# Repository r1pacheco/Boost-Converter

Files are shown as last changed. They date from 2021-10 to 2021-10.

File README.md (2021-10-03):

# Boost-Converter

<h3>This board was designed specifically for the R3 rover and has major restraints that were followed: </h3>

* Maximum dimensions of 42mm x 48mm x 23mm to remain inside the restrictions of the PDB (Power Distribution Board)
* Header space is required so parts do not overlap or bump edges as it is a tight fit within the chasis and the Molex connectors 
* Needs to handle a minimum of 5 amps and increase voltage from 15 to 24 volts minimum (my actual design uses a 5KΩ potentiometer to vary the desired voltage at the output, to make it more flexible for future use if needed)

|Top Side|Bottom Side|
|---|---|
|boost-board-top|boost-board-bot|  

*Click the above photos for a larger view*

<h3>Details and considerations made to improve the boards design and functionality:</h3>

* Thick traces or polygons are used to handle large current as well as act as heat displacers 
* Room for large external heat sinks was needed to help cool down the MOSFET and large diode on the board since they handle the bulk of the current
* Vias were also used to help give direct air flow to the main IC and fuse holder 
* a physical cutout (notch) was placed in the PCB beside the horizontal fuse holder, making it easier to set/remove the fuses (they can be tight sometimes)
* Large polygons were used where the most current would travel to make sure traces did not burn up and can disipate as much heat as possible
* all large capacitors/inductors were kept to one side of the board so they would not interfere with external Molex connectors on the PDB board. This is needed since the right side of the board will be overlapping pre-existing components and we needed the compensated space
* LED indication tells the user if the board is being used and is working properly
* overall board size was given tolerances of 1mm x 1mm x 1mm so they did not interfere with other external boards. Chamfers were also added for the same reason

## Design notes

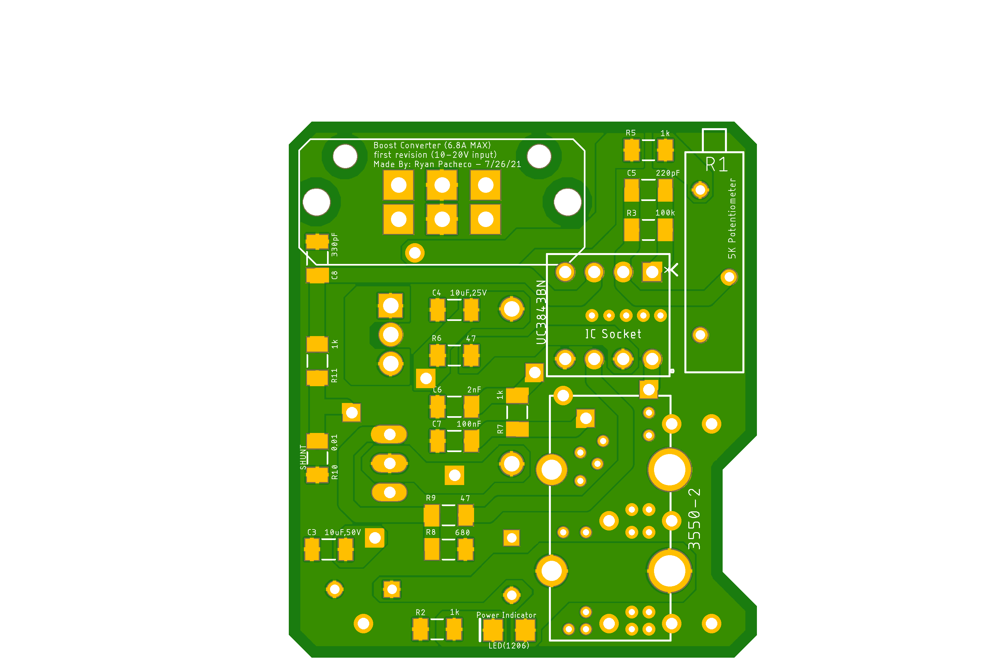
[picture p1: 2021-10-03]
photos/boost-board-top.png

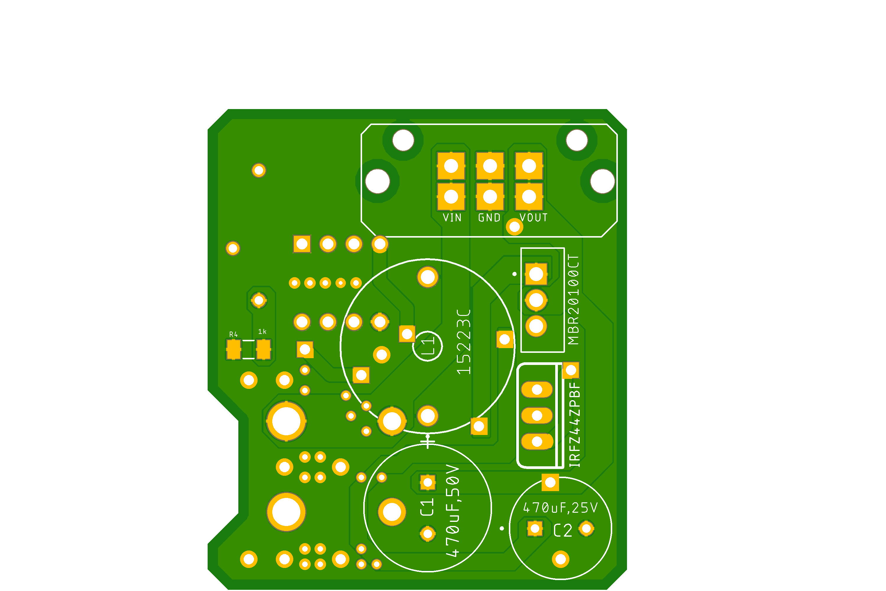
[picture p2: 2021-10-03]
photos/boost-board-bot.png

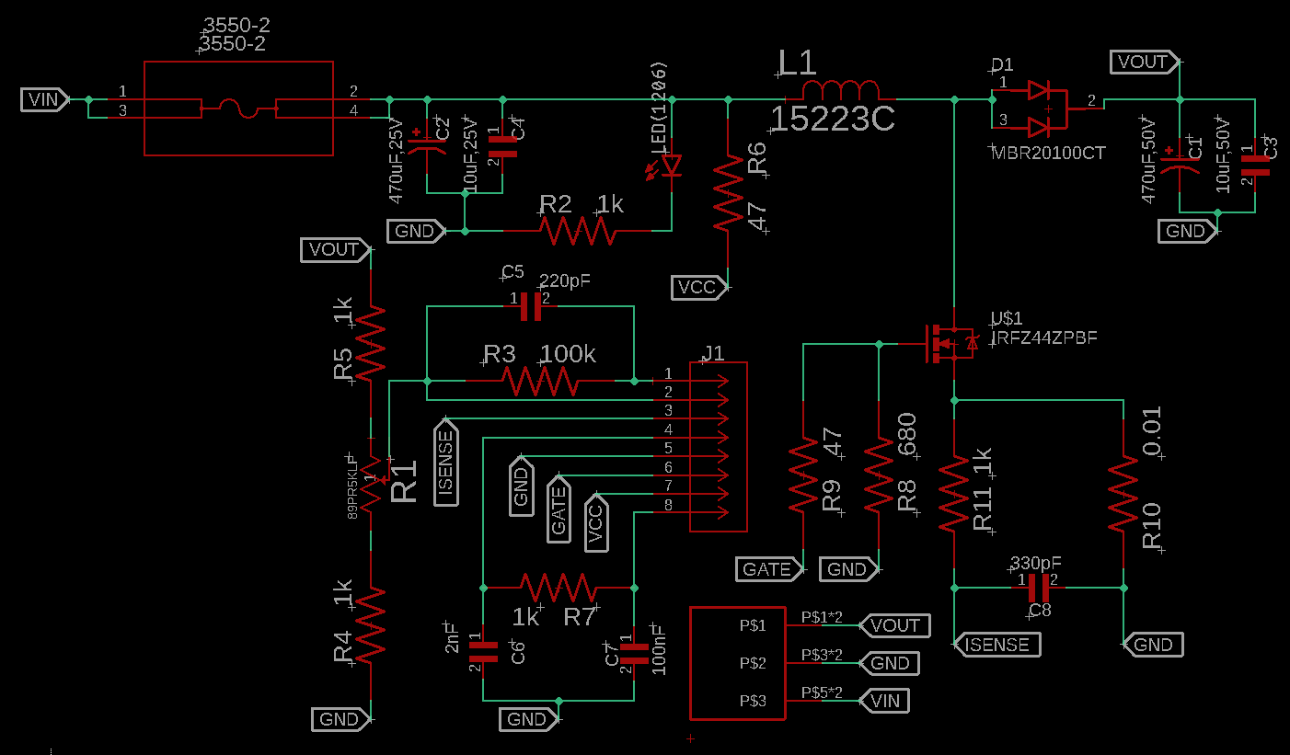
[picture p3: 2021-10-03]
photos/Boost_schm.png

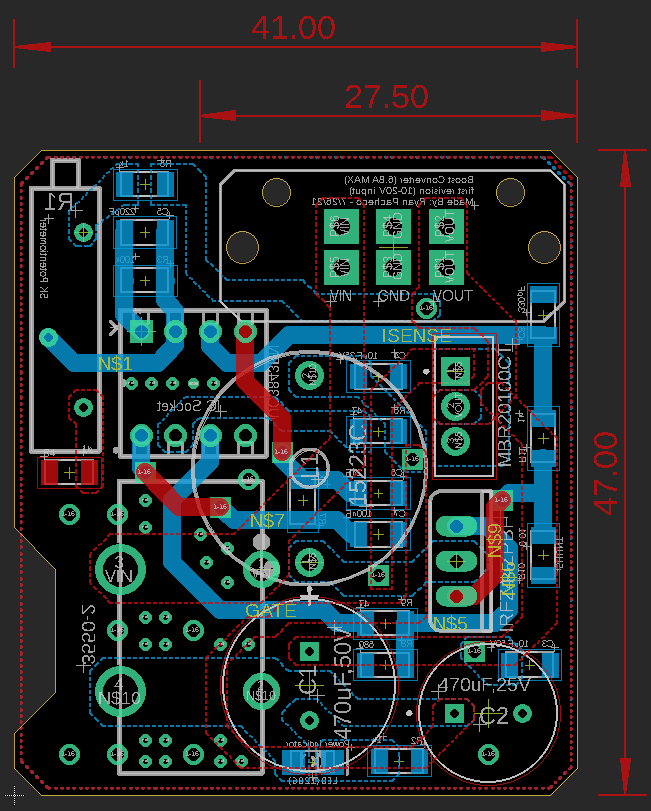
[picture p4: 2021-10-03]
photos/Boost_brd.png

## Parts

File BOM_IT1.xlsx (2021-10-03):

PARTS | SUPPLIER | PRICE | LINK
Fuse Holder | DigiKey | $1.83 | https://www.digikey.ca/en/products/detail/keystone-electronics/3550-2/2137310
Fuse | DigiKey | $0.39 | https://www.digikey.ca/en/products/detail/littelfuse-inc/029707-5WXNV/146586
IC Socket | DigiKey | $0.27 | https://www.digikey.ca/en/products/detail/amphenol-fci/DILB8P-223TLF/4292069?productid=4292069
Switcher/Regulator IC | DigiKey | $1.31 | https://www.digikey.ca/en/products/detail/stmicroelectronics/UC3843BN/1665279
Diode Rectifier (Schottky) | DigiKey | $1.99 | https://www.digikey.ca/en/products/detail/on-semiconductor/MBRF30L45CTG/1792235
N-CH Mosfet | DigiKey | $1.36 | https://www.digikey.ca/en/products/detail/infineon-technologies/IRFZ44ZPBF/811766
Inductor (22uH) | DigiKey | $2.48 | https://www.digikey.ca/en/products/detail/murata-power-solutions-inc/15223C/5798142
Input Cap (electrolytic, 470uF, 25V) | DigiKey | $0.81 | https://www.digikey.ca/en/products/detail/rubycon/25YXG470MEFCT810X16/9553868
Output Cap (electrolytic, 470uF, 50V) | DigiKey | $1.35 | https://www.digikey.ca/en/products/detail/rubycon/50YXG470MEFC12-5X20/3564033
Resistor Trimmer (5K) | DigiKey | $2.49 | https://www.digikey.ca/en/products/detail/tt-electronics-bi/89PR5KLF/2408743
Resistor Shunt (10mOhm) | DigiKey | $0.80 | https://www.digikey.ca/en/products/detail/riedon/CSR1206-0R01F1/2813292
Random Resistors (1206 size) | DigiKey
Random Capacitors (1206 size) | DigiKey
heat sink | DigiKey |  | https://www.digikey.ca/en/products/detail/cui-devices/HSE-B20350-NP/7319885
heat sink | DigiKey |  | https://www.digikey.ca/en/products/detail/assmann-wsw-components/V7236A1/3476149
TOTAL | - | $15.08 | (not including PCB price)

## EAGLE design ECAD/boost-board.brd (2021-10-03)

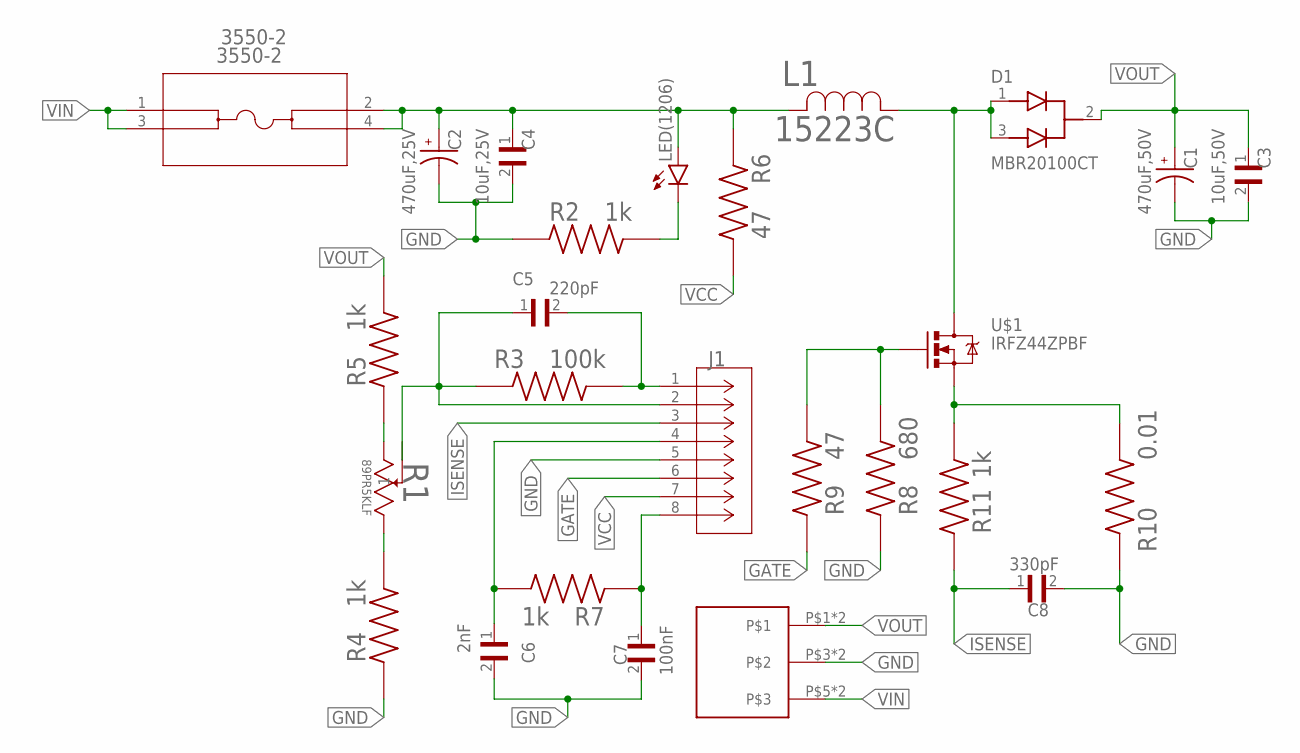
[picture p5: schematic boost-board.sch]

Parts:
3550-2: 3550-2; 3550-2_KEY
C1: 470uF,50V; CAPPRD500W60D1250H2200
C2: 470uF,25V; CAPPRD500W60D1000H1800
C3: 10uF,50V; CAPC3216X88N
C4: 10uF,25V; CAPC3216X88N
C5: 220pF; CAPC3216X88N
C6: 2nF; CAPC3216X88N
C7: 100nF; CAPC3216X88N
C8: 330pF; CAPC3216X88N
D1: MBR20100CT; TO254P1066X482X2286-3
J1: DILB8P-223TLF; CONN_DILB8P-223TLF_AMP
L1: 15223C; 15223C_MUR
LED(1206): LED-FKIT-1206; FKIT-LED-1206
R1: 89PR5KLF; RES3_89P_TTE
R2, R4, R5, R7, R11: 1k; RESC3216X70N
R3: 100k; RESC3216X70N
R6, R9: 47; RESC3216X70N
R8: 680; RESC3216X70N
R10: 0.01; RESC3216X70N
U$1: IRFZ44ZPBF; TO-220
U$2: FX30B-3S-3.81DSA; FX30B-4S-3.81DSA

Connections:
GATE: J1.6, R9.1
GND: C1.N, C2.N, C3.2, C4.2, C6.2, C7.2, C8.2, J1.5, R2.1, R4.1, R8.1, R10.1, U$2.P$3, U$2.P$4
ISENSE: C8.1, J1.3, R11.1
unnamed: C5.1, J1.2, R1.2, R3.1
unnamed: C5.2, J1.1, R3.2
unnamed: R1.1 (3), R4.2
unnamed: R1.3 (1), R5.1
unnamed: R8.2, R9.2, U$1.1 (G)
unnamed: D1.1 (ANODE1), D1.3 (ANODE2), L1.1, U$1.2 (D)
unnamed: C7.1, J1.8, R7.1
unnamed: LED(1206).C, R2.2
unnamed: R10.2, R11.2, U$1.3 (S)
unnamed: 3550-2.2, 3550-2.4, C2.P, C4.1, L1.2, LED(1206).A, R6.2
unnamed: C6.1, J1.4, R7.2
VCC: J1.7, R6.1
VIN: 3550-2.1, 3550-2.3, U$2.P$5, U$2.P$6
VOUT: C1.P, C3.1, D1.2 (COMMON_CATHODE), R5.2, U$2.P$1, U$2.P$2

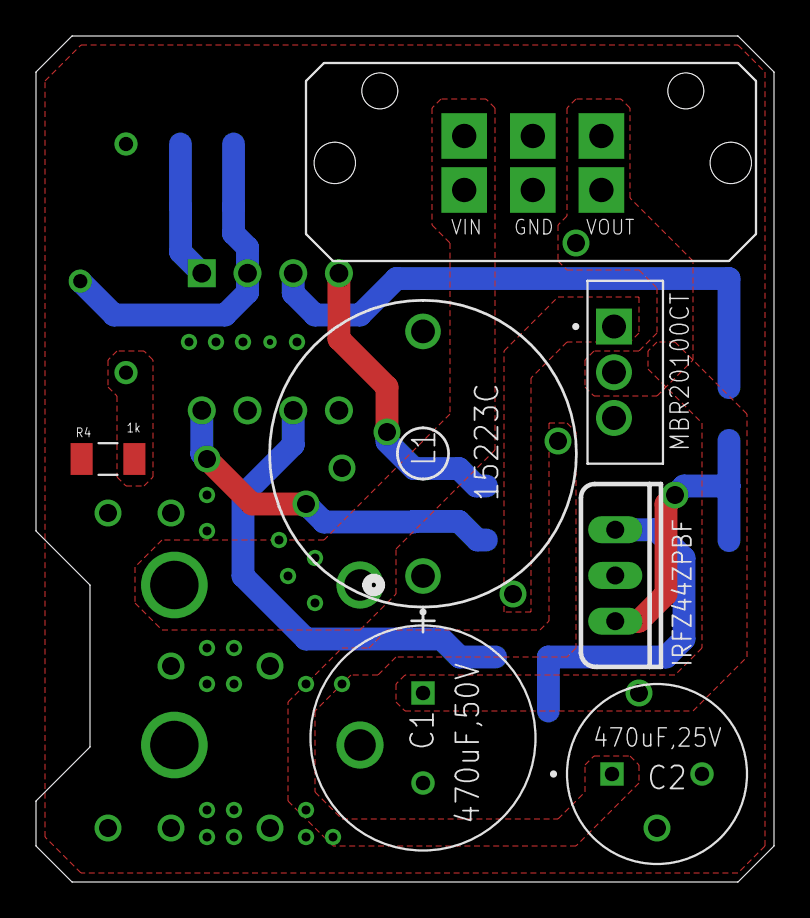
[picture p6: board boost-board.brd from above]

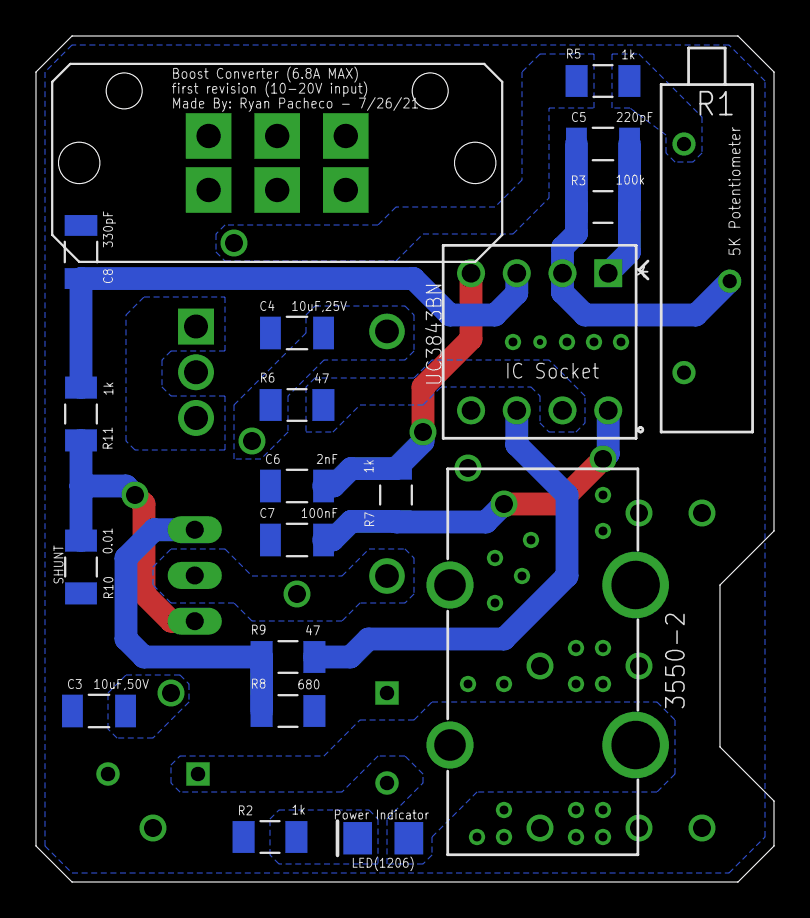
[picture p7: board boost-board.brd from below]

Board: 2 copper layers, 41.0 x 47.0 mm, 26 parts (20 on the bottom side), 17 nets.

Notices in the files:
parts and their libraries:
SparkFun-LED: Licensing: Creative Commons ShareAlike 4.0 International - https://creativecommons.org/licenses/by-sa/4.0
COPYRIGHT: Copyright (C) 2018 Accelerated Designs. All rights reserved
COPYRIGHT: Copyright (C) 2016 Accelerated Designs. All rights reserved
